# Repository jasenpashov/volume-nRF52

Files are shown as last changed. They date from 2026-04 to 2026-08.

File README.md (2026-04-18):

# 🔊 Bluetooth Audio Knob (nRF52840)







---

> 💡 **Note:** This project is far from perfect and there is a lot of room for improvement.
> The goal is not to be a polished product — but to **inspire someone** to build something similar or take it further.

> 🤖 **AI-assisted project:** The code was written using [claude.ai](https://claude.ai), [chatgpt.com](https://chatgpt.com) and [gemini.google.com](https://gemini.google.com) (vibe coding).
> This README and the project description were also generated with their help.

---

## 📸 Preview

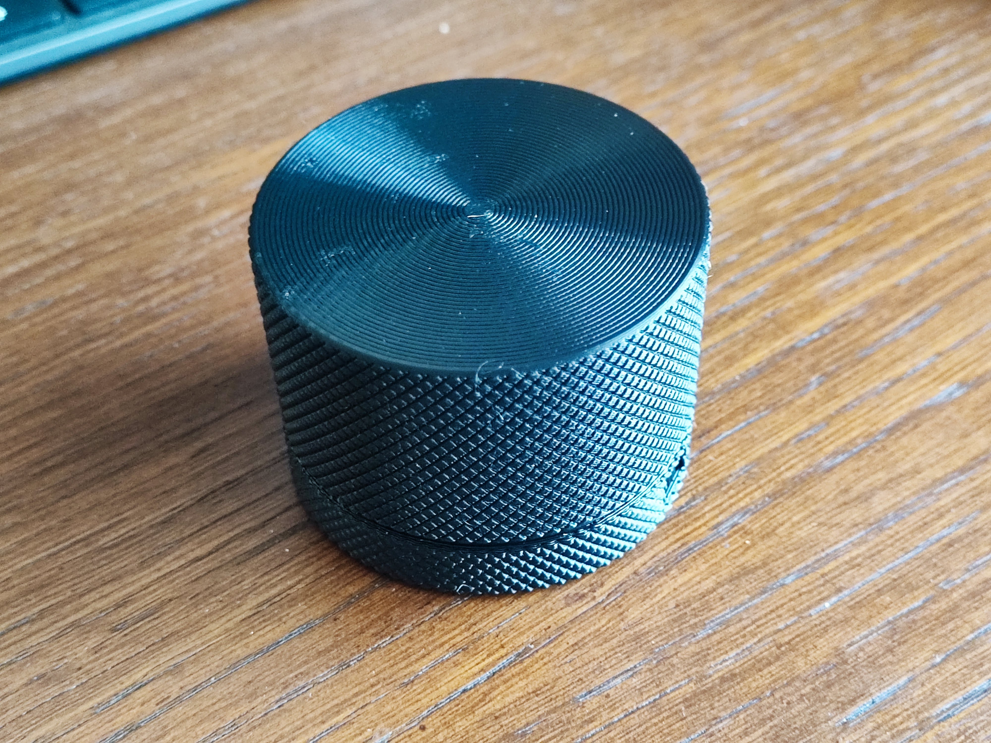
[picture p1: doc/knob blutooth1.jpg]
Bluetooth Knob


| | |
|---|---|
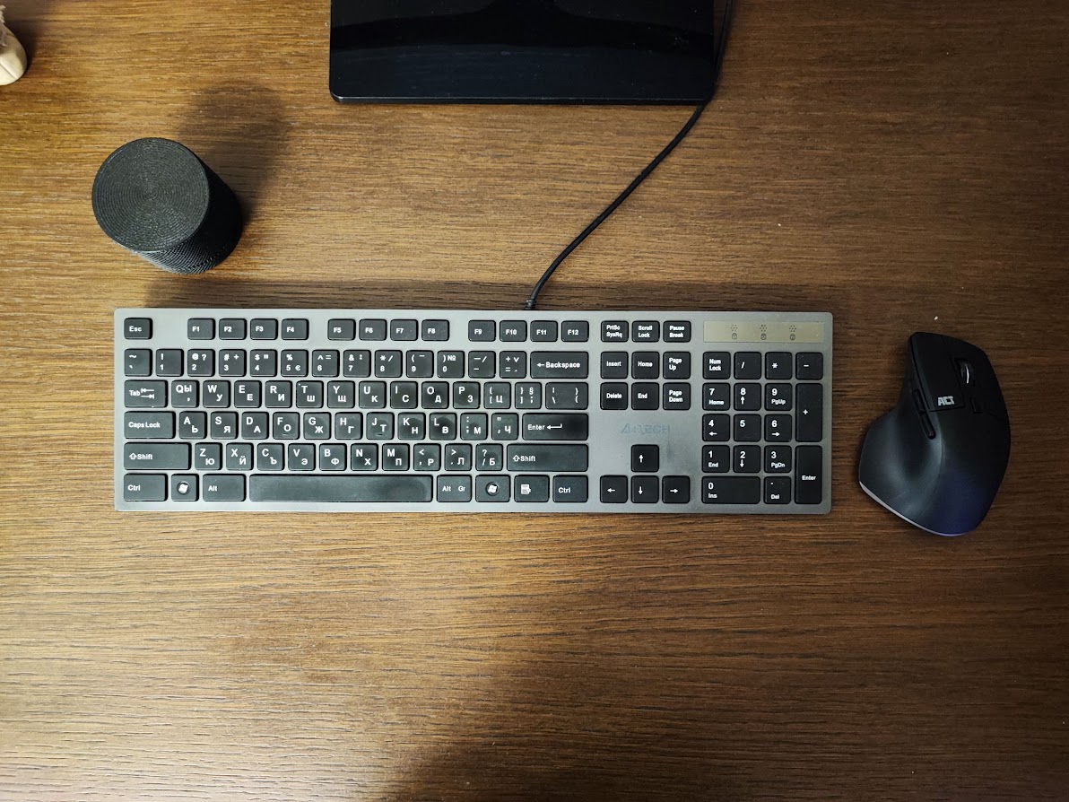
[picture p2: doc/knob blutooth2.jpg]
View 2
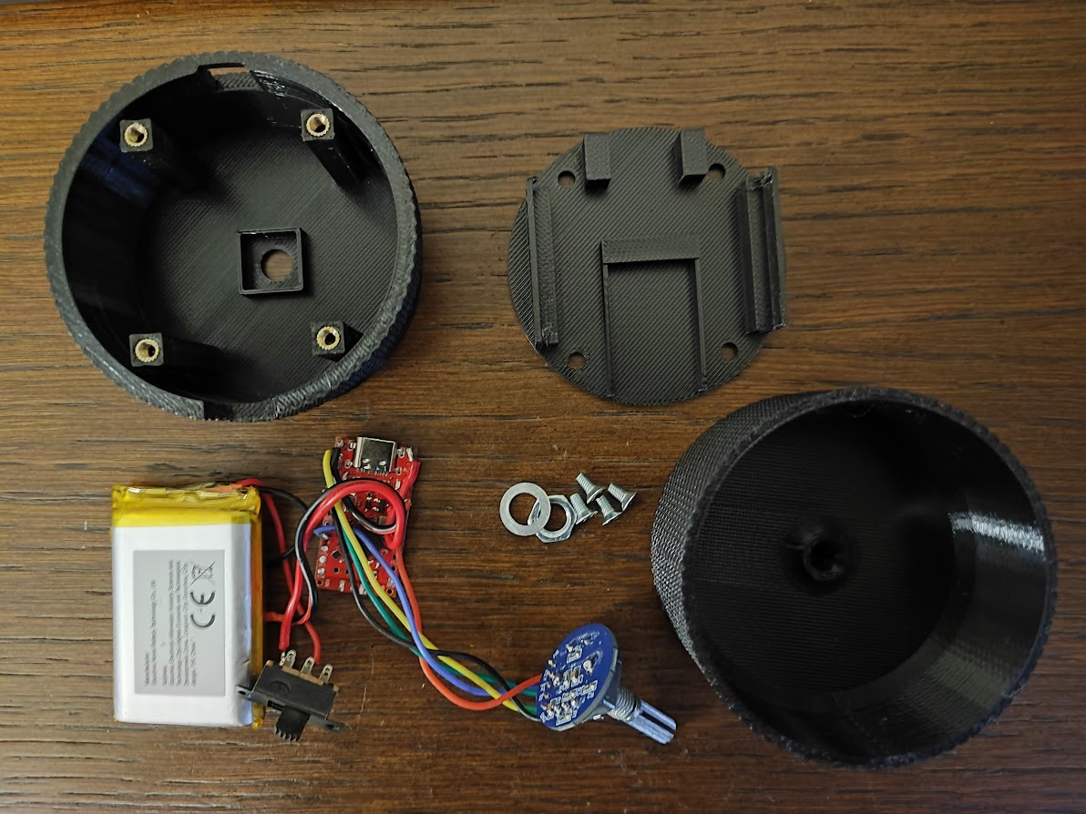
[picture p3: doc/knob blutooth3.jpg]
View 3
|  |  |

---

## 🧠 Description

A wireless rotary encoder knob that connects via Bluetooth to a computer or Android device and controls audio.

- Rotate → Volume Up / Down
- Press → Mute + Play/Pause

Uses standard BLE HID commands — **no additional software required**.

> ⚠️ On Windows, there is occasional instability when the battery is low. The device may need to be removed and re-paired.

---

## 🚀 Features

- 🔊 **BLE HID media controller** — works as a Bluetooth keyboard (media keys)
- ⚡ **Low power design** — battery lasts **7–10 days**
- 🔄 **Interrupt-based encoder reading** — smooth and responsive
- 🖥️ **Compatible with Windows & Android** — no drivers required
- 🖨️ **3D printable enclosure** included

---

## 🎮 Controls

| Action | Function |
|---|---|
| Rotate clockwise | Volume up |
| Rotate counter-clockwise | Volume down |
| Press (short) | Mute |
| Press (long) | Play / Pause |

---

## ⚡ Power Optimization

The project was initially built using an **ESP32 Ultra Mini**, but battery life was only ~24 hours.

👉 **[OLD Volume Control Project](https://github.com/jasenpashov/PC-Volume-Control)**

After switching to **nRF52840**:

- Significantly lower power consumption
- Battery life: **~7–10 days** (depending on signal strength)

---

## 🔧 Hardware

| Component | Price |
|---|---|
| EC11 Rotary Encoder | ~1.90 EUR |
| 103450 3.7V 2000mAh Battery | ~2.50 EUR |
| nRF52840 Pro Micro (Tenstar Robot) | ~6.81 EUR |
| DPDT Slide Switch 2P2T 125VAC (Toggle Switch 2 Position 6 Pins, 5mm handle) | ~1.70 EUR / 10 pcs |

### Photos

| Encoder | nRF52840 | Battery | Slide Switch |
|---|---|---|---|
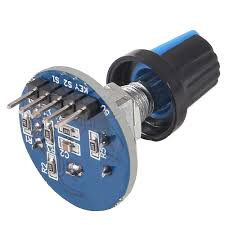
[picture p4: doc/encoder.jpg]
Encoder
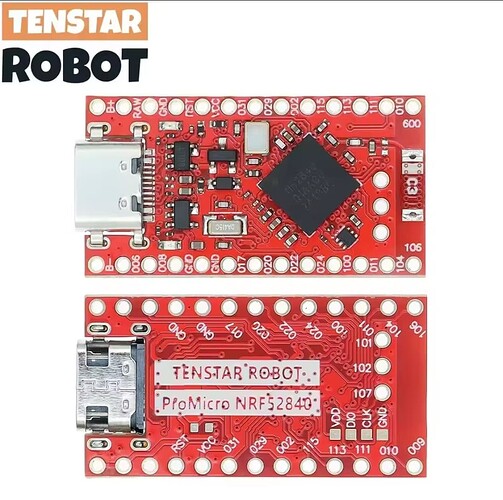
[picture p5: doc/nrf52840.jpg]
nRF52840
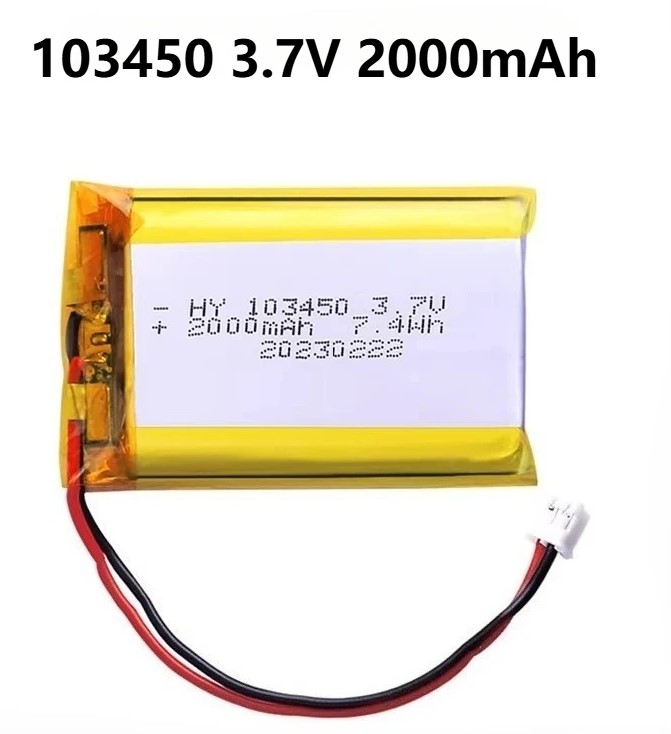
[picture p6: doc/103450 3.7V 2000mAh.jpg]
Battery
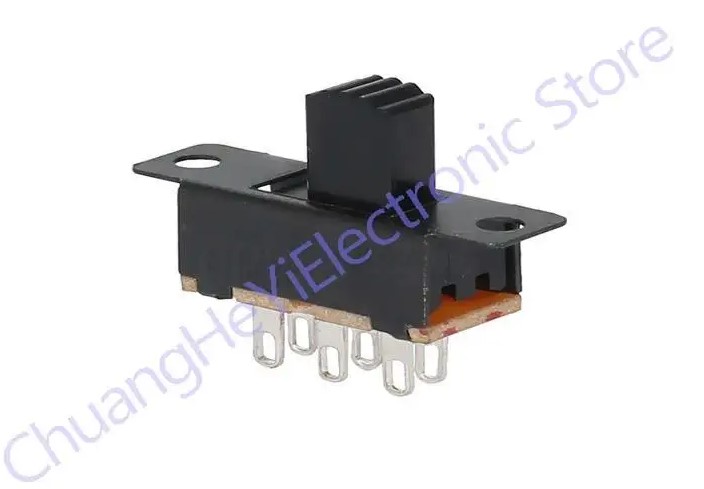
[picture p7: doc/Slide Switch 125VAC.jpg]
Slide Switch
|  |  |  |  |

---

## 🔌 Electrical Diagram

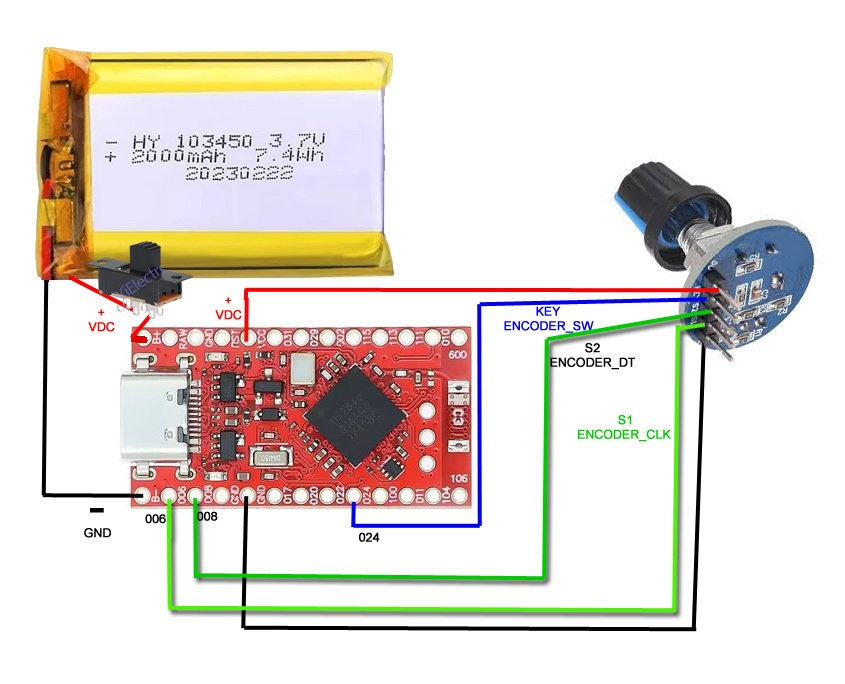
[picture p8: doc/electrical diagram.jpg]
Electrical Diagram


---

## ⚠️ Pin Mapping Issue

The board is an Adafruit clone — pin mapping does **not** match standard documentation.

Discovered mapping:

```cpp
TEST_PIN 12  ->  0.08
         11  ->  0.06
          7  ->  1.02
          3  ->  1.15  (D18)
          2  ->  0.10  (D16)
          1  ->  0.24  (D5)
```

---

## 💾 Firmware Upload (UF2)

> 💾 **Recovery tip:** A pre-built `firmware.uf2` is included in this repo.
> If the board gets into a broken state after experiments or failed flashes and you can no longer upload via USB-to-Serial,
> use boot mode (double-tap reset) to mount it as a USB drive and drag & drop the included `firmware.uf2` to restore it.

### 1. Convert HEX → UF2

Using PlatformIO's bundled tool:

```bash
python "$env:USERPROFILE\.platformio\packages\framework-arduinoadafruitnrf52\tools\uf2conv\uf2conv.py" \
  -c -f 0xada52840 -o firmware.uf2 firmware.hex
```

Or if `uf2conv.py` is in your PATH:

```bash
uf2conv.py -c -f 0xada52840 -o firmware.uf2 firmware.hex
```

### 2. Enter Boot Mode

1. **Double-tap** the reset button (RST → GND rapidly)
2. The device will appear as a **USB mass storage drive**
3. **Drag & drop** `firmware.uf2` onto the drive
4. The device reboots automatically ✅

---

## 🖨️ 3D Models

STL files are included in the `/stl` directory:

| File | Description | Download |
|---|---|---|
| `knob blutooth1.stl` | Enclosure part 1 | [⬇ Download](stl/knob%20blutooth1.stl) |
| `knob blutooth2.stl` | Enclosure part 2 | [⬇ Download](stl/knob%20blutooth2.stl) |
| `knob blutooth3.stl` | Knob cap | [⬇ Download](stl/knob%20blutooth3.stl) |
| `volume knob project.f3d` | Full Fusion 360 source project | [⬇ Download](stl/volume%20knob%20project.f3d) |

> 🖊️ The `.f3d` file contains the **complete Fusion 360 project** with all bodies, sketches and parameters.
> Feel free to open it, modify the dimensions, adapt it to different components, or redesign it entirely to suit your needs.

---

## 🛠️ Build & Development

This project uses **PlatformIO** with the Adafruit nRF52 framework.

```ini
; platformio.ini example
[env:nrf52840]
platform = nordicnrf52
board = adafruit_feather_nrf52840
framework = arduino
```

---

## 📝 Source Code

Full source — `src/main.cpp`:

```cpp
#include <Arduino.h>
#include <bluefruit.h>

// ── Pin definitions (clone board — pins differ from standard Adafruit docs) ──
#define ENCODER_CLK 11  // GPIO 0.06
#define ENCODER_DT  12  // GPIO 0.08
#define ENCODER_SW   1  // GPIO 0.24
#define LED_PIN     15

// Minimum ms between button presses to avoid bouncing
#define SW_DEBOUNCE_MS 350

// ── BLE service objects ──
BLEDis         bledis;   // Device Information Service (manufacturer, model)
BLEHidAdafruit blehid;   // HID service — sends media keys to the host
BLEBas         blebas;   // Battery Level Service

// ── Encoder state (volatile — modified inside interrupt) ──
volatile int encoderDelta = 0;  // Accumulated rotation steps (+/-)
volatile int lastClkState;      // Last known CLK pin state
bool isMuted = false;           // Tracks mute/unmute toggle state

volatile uint32_t lastSwPress = 0;  // Timestamp of last button press (debounce)

// ── Interrupt handler — called on every CLK edge ──
// Compares CLK and DT to determine rotation direction
void readEncoder()
{
    int clkState = digitalRead(ENCODER_CLK);
    if (clkState != lastClkState)
    {
        if (digitalRead(ENCODER_DT) != clkState)
            encoderDelta++;   // Clockwise → volume up
        else
            encoderDelta--;   // Counter-clockwise → volume down

        lastClkState = clkState;
    }
}

// ── Setup — runs once on power-on / reset ──
void setup()
{
    delay(2000);  // Give USB/serial time to initialize

    // LED off by default
    pinMode(LED_PIN, OUTPUT);
    digitalWrite(LED_PIN, LOW);

    // Configure encoder pins
    pinMode(ENCODER_CLK, INPUT);
    pinMode(ENCODER_DT,  INPUT);
    pinMode(ENCODER_SW,  INPUT_PULLUP);  // Button: LOW = pressed

    // Capture initial CLK state and attach interrupt
    lastClkState = digitalRead(ENCODER_CLK);
    attachInterrupt(digitalPinToInterrupt(ENCODER_CLK), readEncoder, CHANGE);

    // ── BLE initialization ──
    Bluefruit.begin();
    Bluefruit.setTxPower(6);               // TX power in dBm (range: -40 … +8)
    Bluefruit.setName("nRF52-Volume-LowPower");

    // Connection interval: 100–200 ms (balances latency vs. power consumption)
    Bluefruit.Periph.setConnInterval(80, 160);

    // Device info (appears in OS Bluetooth device list)
    bledis.setManufacturer("Logitech");
    bledis.setModel("nRF52-HID");
    bledis.begin();

    // Battery service — reports 100% (static, no actual measurement)
    blebas.begin();
    blebas.write(100);

    // HID service — handles all media key presses
    blehid.begin();

    // ── BLE advertising setup ──
    Bluefruit.Advertising.addFlags(BLE_GAP_ADV_FLAGS_LE_ONLY_GENERAL_DISC_MODE);
    Bluefruit.Advertising.addAppearance(0x03C1);  // HID Keyboard appearance
    Bluefruit.Advertising.addService(blehid);
    Bluefruit.Advertising.addService(blebas);
    Bluefruit.ScanResponse.addName();

    Bluefruit.Advertising.restartOnDisconnect(true);   // Auto re-advertise on disconnect
    Bluefruit.Advertising.setInterval(2048, 2048);      // Slow advertising = lower power
    Bluefruit.Advertising.start(0);                     // Advertise indefinitely
}

// ── Main loop — runs repeatedly ──
void loop()
{
    // Sleep until event if not connected (saves power)
    if (!Bluefruit.connected())
    {
        sd_app_evt_wait();
        return;
    }

    // ── Button handler — Mute + Play/Pause toggle ──
    if (digitalRead(ENCODER_SW) == LOW)
    {
        uint32_t now = millis();
        if ((now - lastSwPress) > SW_DEBOUNCE_MS)
        {
            lastSwPress = now;

            // Both mute and unmute send the same two keys — toggle tracked in isMuted
            blehid.consumerKeyPress(HID_USAGE_CONSUMER_MUTE);
            delay(10);
            blehid.consumerKeyRelease();
            delay(10);
            blehid.consumerKeyPress(HID_USAGE_CONSUMER_PLAY_PAUSE);
            delay(10);
            blehid.consumerKeyRelease();

            isMuted = !isMuted;
        }
    }

    // ── Encoder handler — Volume Up / Down ──
    if (abs(encoderDelta) >= 1)
    {
        // Safely read and reset delta outside interrupt context
        noInterrupts();
        int delta = encoderDelta;
        encoderDelta = 0;
        interrupts();

        uint16_t key = (delta > 0)
            ? HID_USAGE_CONSUMER_VOLUME_INCREMENT
            : HID_USAGE_CONSUMER_VOLUME_DECREMENT;

        blehid.consumerKeyPress(key);
        delay(5);
        blehid.consumerKeyRelease();
    }

    // Sleep until next BLE event (SoftDevice low-power wait)
    sd_app_evt_wait();
}
```

---

## 📚 Resources

- [nRF52840 Pro Micro / Nice!Nano — PlatformIO Overview](https://cool-web.de/nrf/nrf52840-promicro-nicenano-board-platformio-vorstellung.htm)
- [Using Pro Micro nRF52840 with Arduino IDE — Arduino Forum](https://forum.arduino.cc/t/using-the-pro-micro-nrf52840-board-with-the-arduino-ide/1347460)

---

## 📄 License

MIT — feel free to use, modify, and share.

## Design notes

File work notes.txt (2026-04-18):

python "$env:USERPROFILE\.platformio\packages\framework-arduinoadafruitnrf52\tools\uf2conv\uf2conv.py" -c -f 0xada52840 -o firmware.uf2 firmware.hex
uf2conv.py -c -f 0xada52840 -o firmware.uf2 firmware.hex

https://cool-web.de/nrf/nrf52840-promicro-nicenano-board-platformio-vorstellung.htm
https://forum.arduino.cc/t/using-the-pro-micro-nrf52840-board-with-the-arduino-ide/1347460

TEST_PIN 12 //12 0.08 ,11 0.06, 7 102 ,3 115 D18,  2=0.10 D16,  1=0.24 D5

Rotary Encoder Module for Arduino Brick Sensor Development Round Audio Rotating Potentiometer Knob Cap EC11 1.9EUR
103450 3.7V 2000mAh  2.5EUR
tenstar robot nrf52840 pro micro 6.81EUR
Toggle Switch 2 Position 6 Pins With Fixed Hole Handle High 5mm DPDT 2P2T Panel Mount Slide Switch 125VAC 0.70EUR

// tenstar robot nrf52840 pro micro

// #include <Arduino.h>
// #include <bluefruit.h>

// const int testPins[] = {1, 2, 3, 4, 5, 6, 7, 8, 9, 10, 11, 12, 13, 14, 15, 16, 17, 18, 19, 20};
// const int numPins = sizeof(testPins) / sizeof(testPins[0]);

// void setup() {
//   Serial.begin(115200);
//   Serial.println("LED scan start");

//   for (int i = 0; i < numPins; i++) {
//     int pin = testPins[i];
//     pinMode(pin, OUTPUT);
//     digitalWrite(pin, HIGH);
//     Serial.print("Testing pin HIGH: ");
//     Serial.println(pin);
//     delay(1000);

//     digitalWrite(pin, LOW);
//     Serial.print("Testing pin LOW: ");
//     Serial.println(pin);
//     delay(1000);
//   }

//   Serial.println("LED scan finished");
// }

// void loop()
// {
//     // нищо не правим в loop
// }

// #include <Arduino.h>
// #include <bluefruit.h>

// #define TEST_PIN 12 //12 0.08 ,11 0.06, 7 102 ,3 115 D18,  2=0.10 D16,  1=0.24 D5

// BLEHidAdafruit blehid;

// unsigned long lastTrigger = 0;
// const unsigned long debounceMs = 500;

// void setup() {
//   Serial.begin(115200);
//   delay(2000);

//   Serial.println("\n=== nRF52840 SINGLE PIN TEST ===");
//   Serial.print("Testing Arduino pin: ");
//   Serial.println(TEST_PIN);
//   Serial.println("Touch GND -> MUTE\n");

//   pinMode(TEST_PIN, INPUT_PULLUP);

//   Bluefruit.begin();
//   Bluefruit.setTxPower(4);
//   Bluefruit.setName("nRF52-PinTest");

//   blehid.begin();

//   Bluefruit.Advertising.addFlags(BLE_GAP_ADV_FLAGS_LE_ONLY_GENERAL_DISC_MODE);
//   Bluefruit.Advertising.addService(blehid);
//   Bluefruit.ScanResponse.addName();
//   Bluefruit.Advertising.start(0);
// }

// void loop() {
//   if (!Bluefruit.connected()) return;

//   if (digitalRead(TEST_PIN) == LOW) {
//     if (millis() - lastTrigger > debounceMs) {
//       lastTrigger = millis();

//       Serial.print("GND detected on pin ");
//       Serial.println(TEST_PIN);

//       blehid.consumerKeyPress(HID_USAGE_CONSUMER_MUTE);
//       blehid.consumerKeyRelease();
//     }
//   }
// }

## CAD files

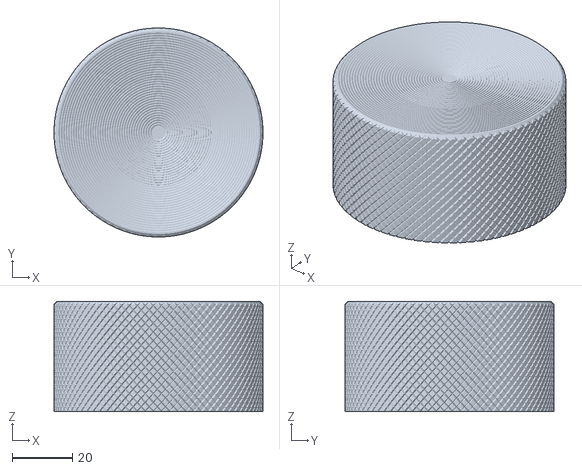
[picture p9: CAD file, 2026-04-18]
doc/knob blutooth1.stl
69.3 x 69.3 x 36.5

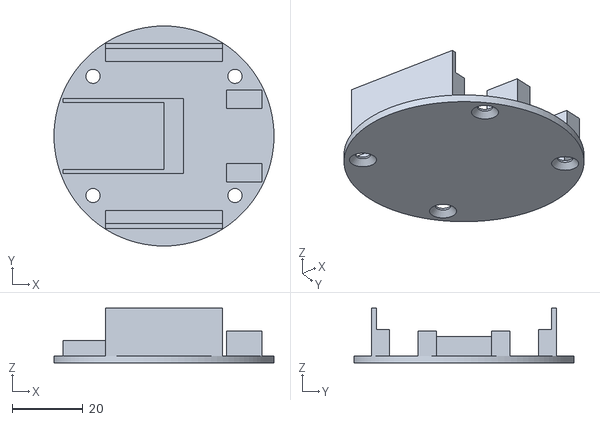
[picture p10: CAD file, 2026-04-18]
doc/knob blutooth3.stl
62.0 x 62.0 x 15.5

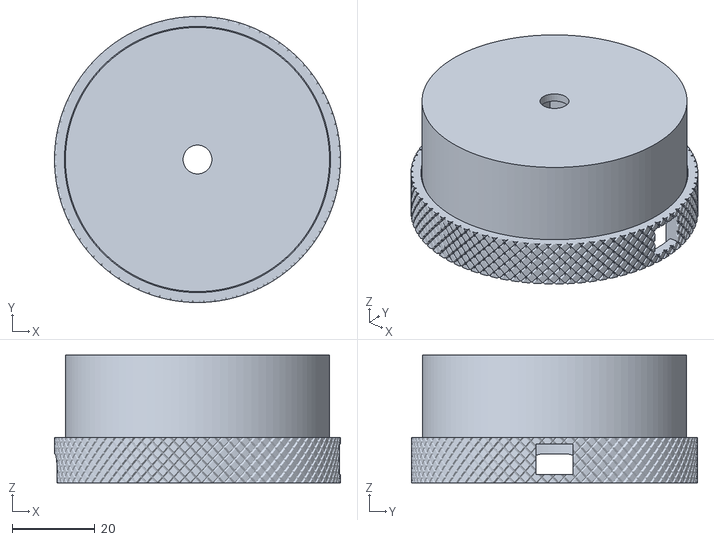
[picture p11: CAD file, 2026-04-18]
doc/knob blutooth2.stl
69.3 x 69.3 x 31.0

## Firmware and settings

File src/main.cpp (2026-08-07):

#include <Arduino.h>
#include <bluefruit.h>

#define ENCODER_CLK 11 //006
#define ENCODER_DT  12 //008
#define ENCODER_SW  1  //0.24
#define LED_PIN     15
#define SW_DEBOUNCE_MS 350

// --- Power-saving connection interval settings ---
// Fast interval: used while the user is actively using the button/encoder
#define CONN_INTERVAL_FAST_MIN 6     // 6 * 1.25ms = 7.5ms
#define CONN_INTERVAL_FAST_MAX 12    // 12 * 1.25ms = 15ms
// Slow interval: used during idle time to save battery
#define CONN_INTERVAL_SLOW_MIN 1600  // 1600 * 1.25ms = 2000ms (2s)
#define CONN_INTERVAL_SLOW_MAX 3200  // 3200 * 1.25ms = 4000ms (4s)
// Idle time before switching to the slow interval
#define IDLE_TIMEOUT_MS (3UL * 60UL * 1000UL) // 3 minutes

BLEDis bledis;
BLEHidAdafruit blehid;
BLEBas blebas;

volatile int encoderDelta = 0;
volatile int lastClkState;
volatile bool activityFlag = false; // set by ISR, handled in loop()

bool isMuted = false;
volatile uint32_t lastSwPress = 0;

uint32_t lastActivity = 0;
bool isSlowMode = false;

void readEncoder()
{
    int clkState = digitalRead(ENCODER_CLK);
    if (clkState != lastClkState)
    {
        if (digitalRead(ENCODER_DT) != clkState)
        {
            encoderDelta++;
        }
        else
        {
            encoderDelta--;
        }
        lastClkState = clkState;
        activityFlag = true; // signal activity, but don't touch BLE here
    }
}

// Switches back to the fast connection interval on activity.
// Called only from loop(), never from an ISR.
void goFast()
{
    if (isSlowMode)
    {
        Bluefruit.Periph.setConnInterval(CONN_INTERVAL_FAST_MIN, CONN_INTERVAL_FAST_MAX);
        isSlowMode = false;
    }
    lastActivity = millis();
}

// Switches to the slow connection interval if there's been no activity for IDLE_TIMEOUT_MS
void goSlowIfIdle()
{
    if (!isSlowMode && (millis() - lastActivity > IDLE_TIMEOUT_MS))
    {
        Bluefruit.Periph.setConnInterval(CONN_INTERVAL_SLOW_MIN, CONN_INTERVAL_SLOW_MAX);
        isSlowMode = true;
    }
}

void setup()
{
    delay(2000);
    pinMode(LED_PIN, OUTPUT);
    digitalWrite(LED_PIN, LOW);
    pinMode(ENCODER_CLK, INPUT);
    pinMode(ENCODER_DT, INPUT);
    pinMode(ENCODER_SW, INPUT_PULLUP);
    lastClkState = digitalRead(ENCODER_CLK);
    attachInterrupt(digitalPinToInterrupt(ENCODER_CLK), readEncoder, CHANGE);

    Bluefruit.begin();
    Bluefruit.setTxPower(6); //-40, -20, -16, -12, -8, -4, 0, +2, +3, +4, +5, +6, +7, +8
    Bluefruit.setName("nRF52-Volume-LowPower");

    // Start directly in "fast" mode (nicer usability on first connection)
    Bluefruit.Periph.setConnInterval(CONN_INTERVAL_FAST_MIN, CONN_INTERVAL_FAST_MAX);

    bledis.setManufacturer("Logitech");
    bledis.setModel("nRF52-HID");
    bledis.begin();

    blebas.begin();
    blebas.write(100);

    blehid.begin();

    Bluefruit.Advertising.addFlags(BLE_GAP_ADV_FLAGS_LE_ONLY_GENERAL_DISC_MODE);
    Bluefruit.Advertising.addAppearance(0x03C1);
    Bluefruit.Advertising.addService(blehid);
    Bluefruit.Advertising.addService(blebas);
    Bluefruit.ScanResponse.addName();
    Bluefruit.Advertising.restartOnDisconnect(true);
    Bluefruit.Advertising.setInterval(2048, 2048);
    Bluefruit.Advertising.start(0);

    lastActivity = millis();
}

void loop()
{
    if (!Bluefruit.connected())
    {
        sd_app_evt_wait();
        return;
    }

    // If there was ISR activity since the last loop, handle it here (BLE-safe context)
    if (activityFlag)
    {
        activityFlag = false;
        goFast();
    }

    if (digitalRead(ENCODER_SW) == LOW)
    {
        uint32_t now = millis();
        if ((now - lastSwPress) > SW_DEBOUNCE_MS)
        {
            lastSwPress = now;
            goFast(); // button press also counts as activity

            if (!isMuted)
            {
                // Mute + pause
                blehid.consumerKeyPress(HID_USAGE_CONSUMER_MUTE);
                delay(10);
                blehid.consumerKeyRelease();
                delay(10);
                blehid.consumerKeyPress(HID_USAGE_CONSUMER_PLAY_PAUSE);
                delay(10);
                blehid.consumerKeyRelease();
                isMuted = true;
            }
            else
            {
                // Unmute + Play
                blehid.consumerKeyPress(HID_USAGE_CONSUMER_MUTE);
                delay(10);
                blehid.consumerKeyRelease();
                delay(10);
                blehid.consumerKeyPress(HID_USAGE_CONSUMER_PLAY_PAUSE);
                delay(10);
                blehid.consumerKeyRelease();
                isMuted = false;
            }
        }
    }

    if (abs(encoderDelta) >= 1)
    {
        noInterrupts();
        int delta = encoderDelta;
        encoderDelta = 0;
        interrupts();

        goFast(); // encoder movement also counts as activity

        uint16_t key = (delta > 0)
                           ? HID_USAGE_CONSUMER_VOLUME_INCREMENT
                           : HID_USAGE_CONSUMER_VOLUME_DECREMENT;
        blehid.consumerKeyPress(key);
        delay(5);
        blehid.consumerKeyRelease();
    }

    // Check whether it's time to switch to the slow (power-saving) mode
    goSlowIfIdle();

    sd_app_evt_wait();
}

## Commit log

2026-03-01 using power-saving interruptions
2026-03-16 V2 power-saving
2026-04-18 V3 mid power
2026-04-18 3d files and notes
    [knob blutooth1.stl, knob blutooth2.stl, knob blutooth3.stl]
2026-04-18 Enhance README with download links for 3D models
    Added download links for STL files in the README.
2026-08-07 feat: switch to slow BLE interval after 3min idle
    Reduces power consumption by increasing connection interval
    from 7.5-15ms to 2-4s after 3 minutes without encoder/button
    activity. Returns to fast interval immediately on interaction.
